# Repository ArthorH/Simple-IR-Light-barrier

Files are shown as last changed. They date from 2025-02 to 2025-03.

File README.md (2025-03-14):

# Simple IR Light barrier
Very simplistic light barrier based on NE555 and TSSP4038 sensor
SimpleRXTX
## Project Status: **completed** 
**Design** ✅ — **Fabrication** ✅ — **Assembly** ✅ — **Bringup** ✅ — **Testing** ✅  
## Key technologies:
&nbsp;&nbsp;&nbsp;&nbsp;
## Features:
- **Adjustable output impulse time**
- **TSSP4038**
- **Universal THT SMD footprints**
  
obraz
## Notice:
TSSP series **IS NOT** pin compatible with TSOP seriers sensors.

**DO NOT** use sensors with continious carrier rejection such as TSOP4838

TSSP/TSOP can reliably detect up to 1KHz modulated signal
## Completed:


## Author:
Artem Horiunov
## License:
CERN-OHL-P

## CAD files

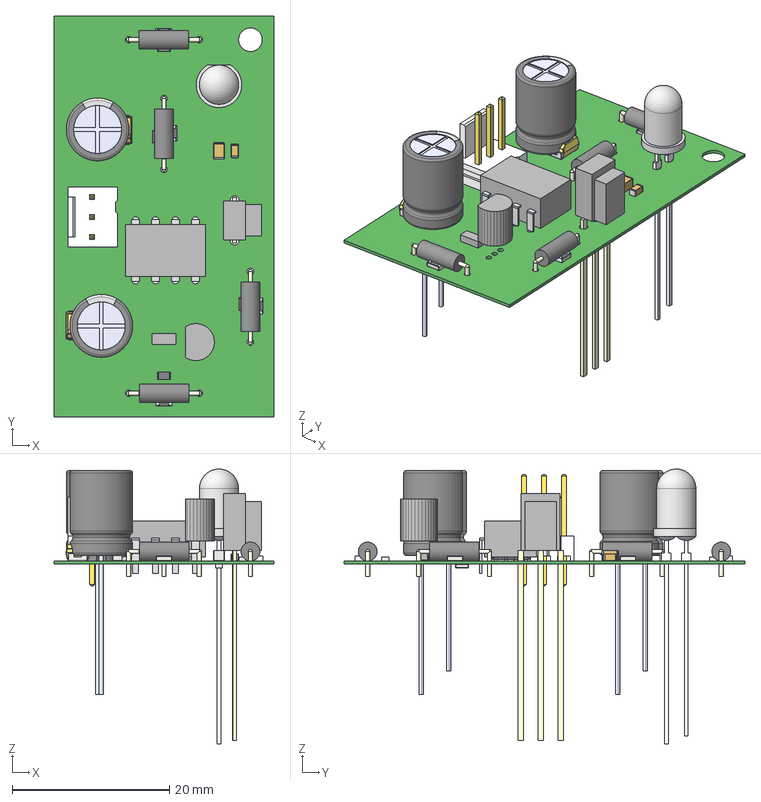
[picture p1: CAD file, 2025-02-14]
Mechanical/RX.step
28.0 x 51.0 x 35.0 mm
Extruded x 32
Molex 22-11-2032 1 new
Molex 22-11-2032 2 x 3
BODY_M08A_35
LEAD_M08A_57 x 8
MANIFOLD_SOLID_BREP_2784
MANIFOLD_SOLID_BREP_2935
MANIFOLD_SOLID_BREP_3086
MANIFOLD_SOLID_BREP_3237
Mid_Body x 5
Mark x 5
RES0805 x 4
151053xxx
Package x 2
Pins x 2
Marking x 2
Logo x 2

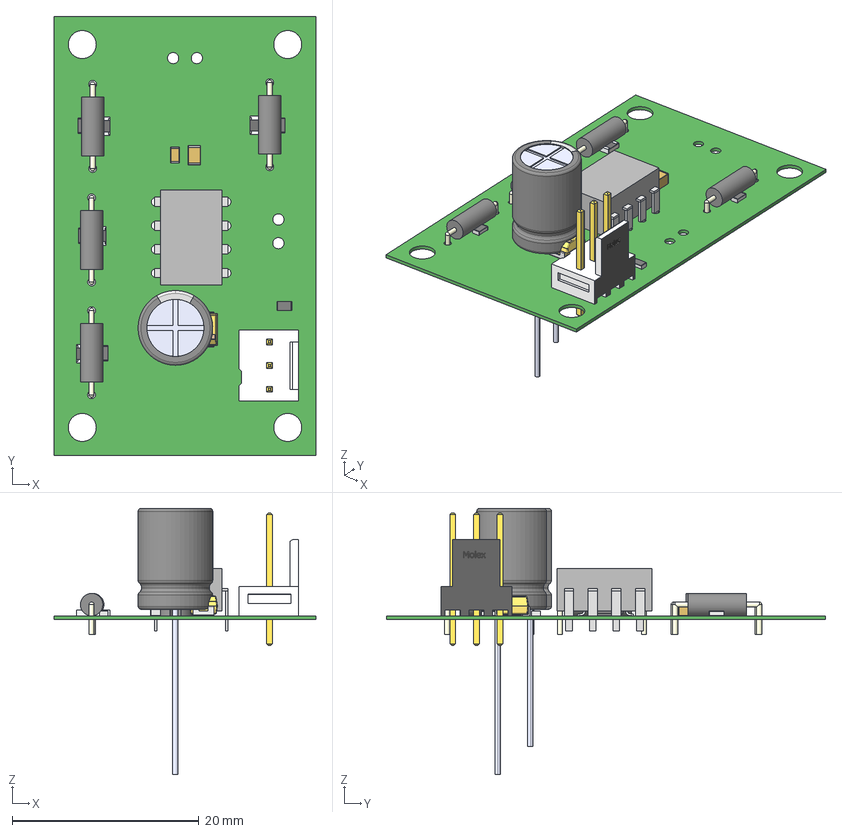
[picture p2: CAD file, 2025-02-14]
Mechanical/TX.step
28.0 x 47.0 x 28.5 mm
Package
Pins
Marking
Logo
Extruded x 25
BODY_M08A_35
LEAD_M08A_57 x 8
MANIFOLD_SOLID_BREP_2784
MANIFOLD_SOLID_BREP_2935
MANIFOLD_SOLID_BREP_3086
MANIFOLD_SOLID_BREP_3237
Mid_Body x 5
Mark x 5
RES0805 x 4
Molex 22-11-2032 1 new
Molex 22-11-2032 2 x 3

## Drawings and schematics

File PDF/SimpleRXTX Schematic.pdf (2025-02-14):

# BC547CG² ¹

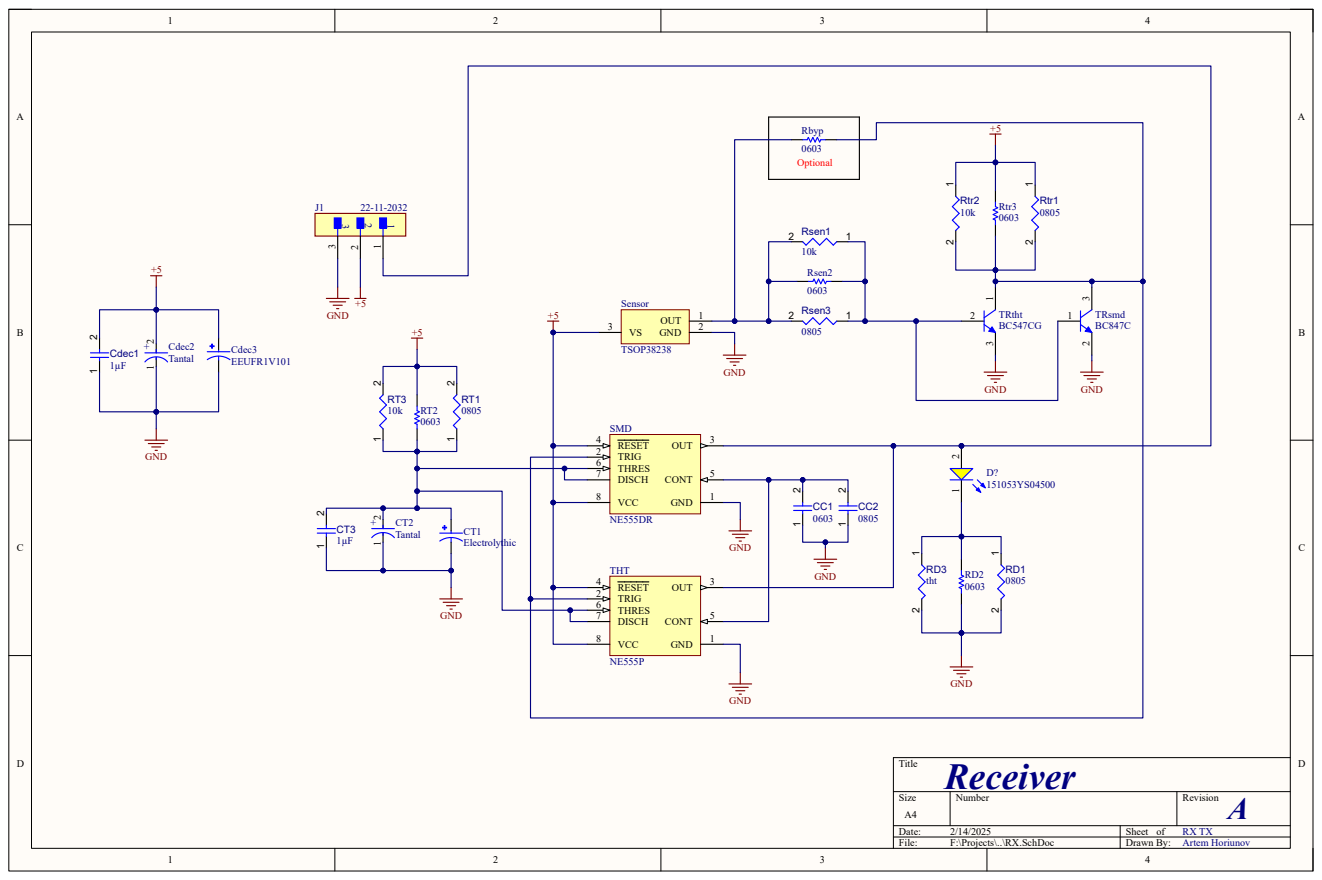
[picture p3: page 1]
Title; Size; Number; Revision; Date:; Sheet of; File:; F:\Projects\..\RX.SchDoc; Drawn By:; GND; TRIG 2; OUT; 3 RESET 4; CONT; THRES 6 DISCH 7; VCC 8; SMD; Sensor; TSOP38238; CT1 Electrolythic; Cdec3; EEUFR1V101; Tantal; GND ²; Rsen3; Rsen2; Rsen1; TRtht; Rtr1 Rtr3; Rtr2; tht; Cdec2; Tantal 1 2; Cdec1; GND 1 2; Rbyp; 0603 Optional; THT; TRsmd BC847C; Artem Horiunov; Receiver

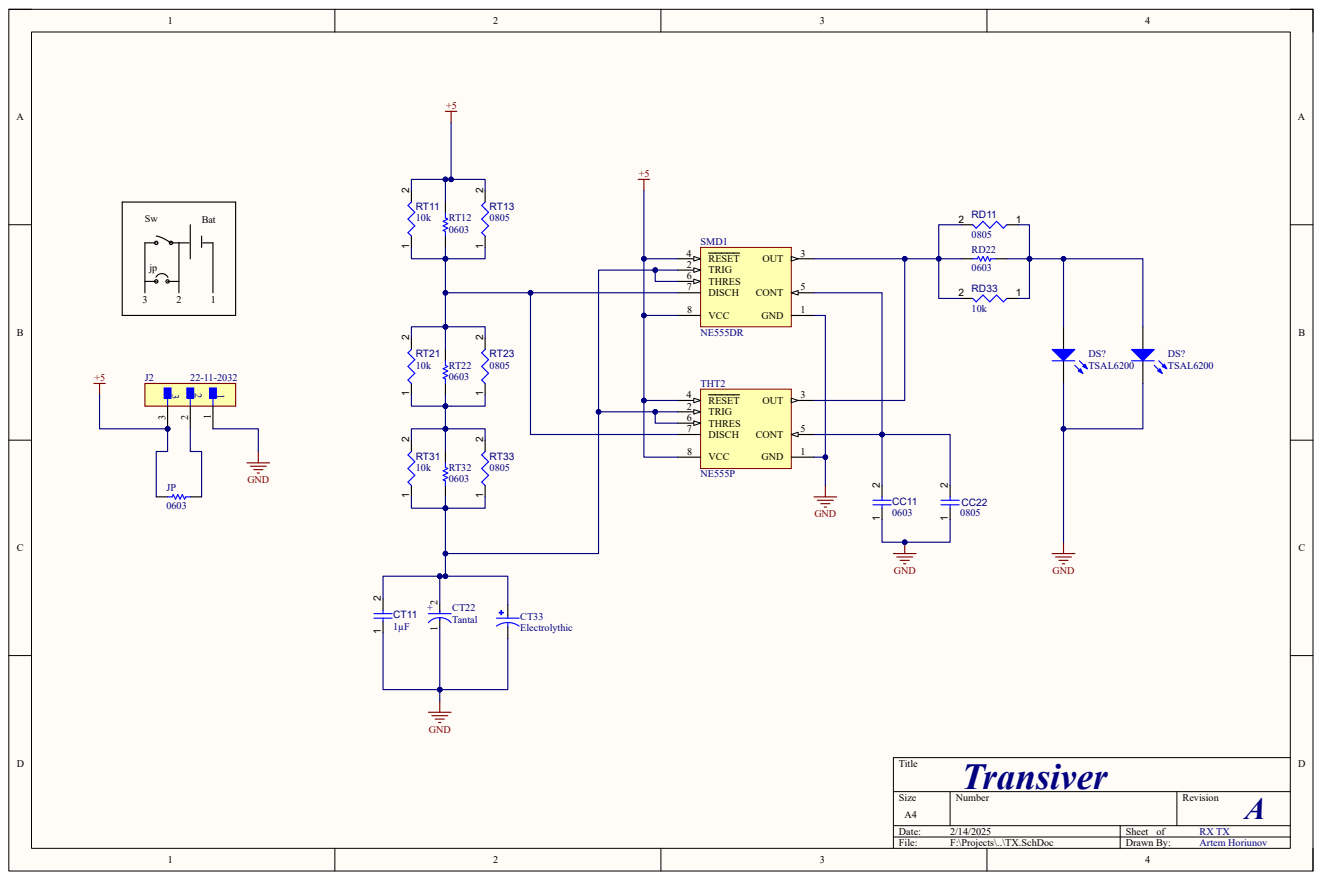
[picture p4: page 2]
Title; Size; Number; Revision; Date:; Sheet of; File:; F:\Projects\..\TX.SchDoc; Drawn By:; GND; TRIG 2; OUT; 3 RESET 4; CONT; THRES 6 DISCH 7; VCC 8; SMD1; THT2; DS? TSAL6200; GND ³; Bat; Electrolythic ²; Tantal 1 2; Artem Horiunov; Transiver

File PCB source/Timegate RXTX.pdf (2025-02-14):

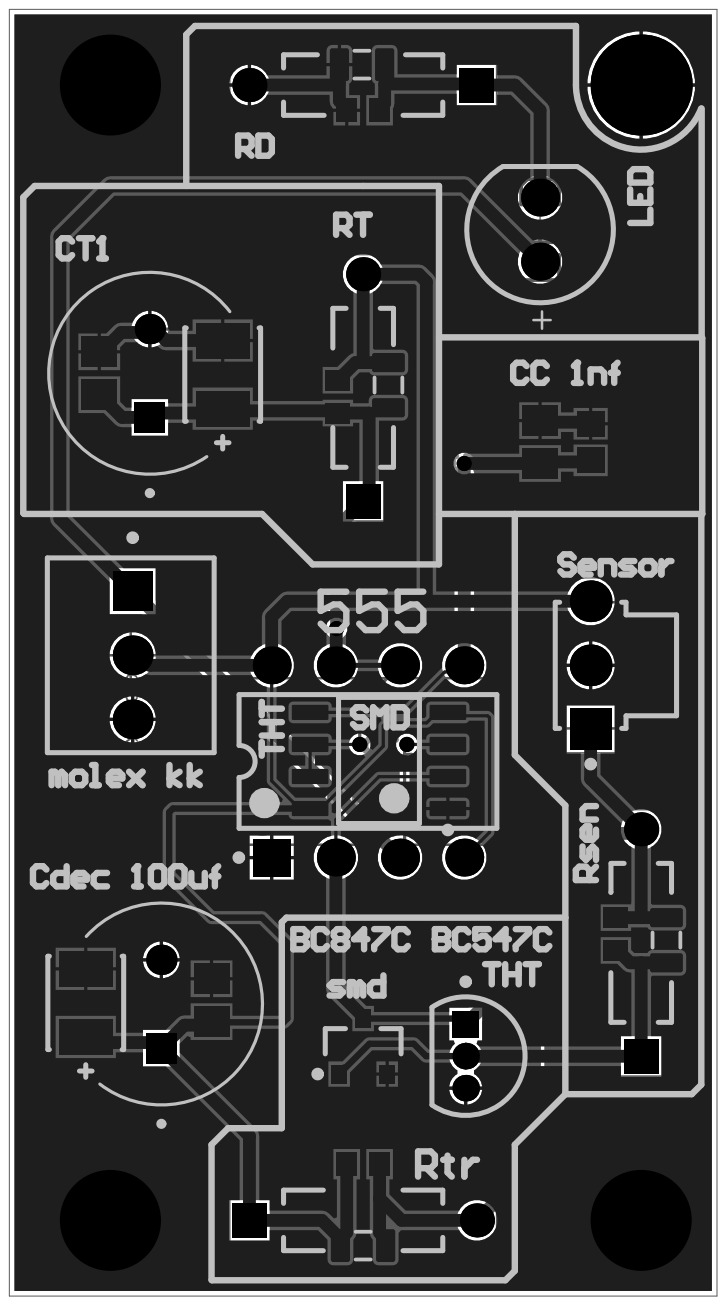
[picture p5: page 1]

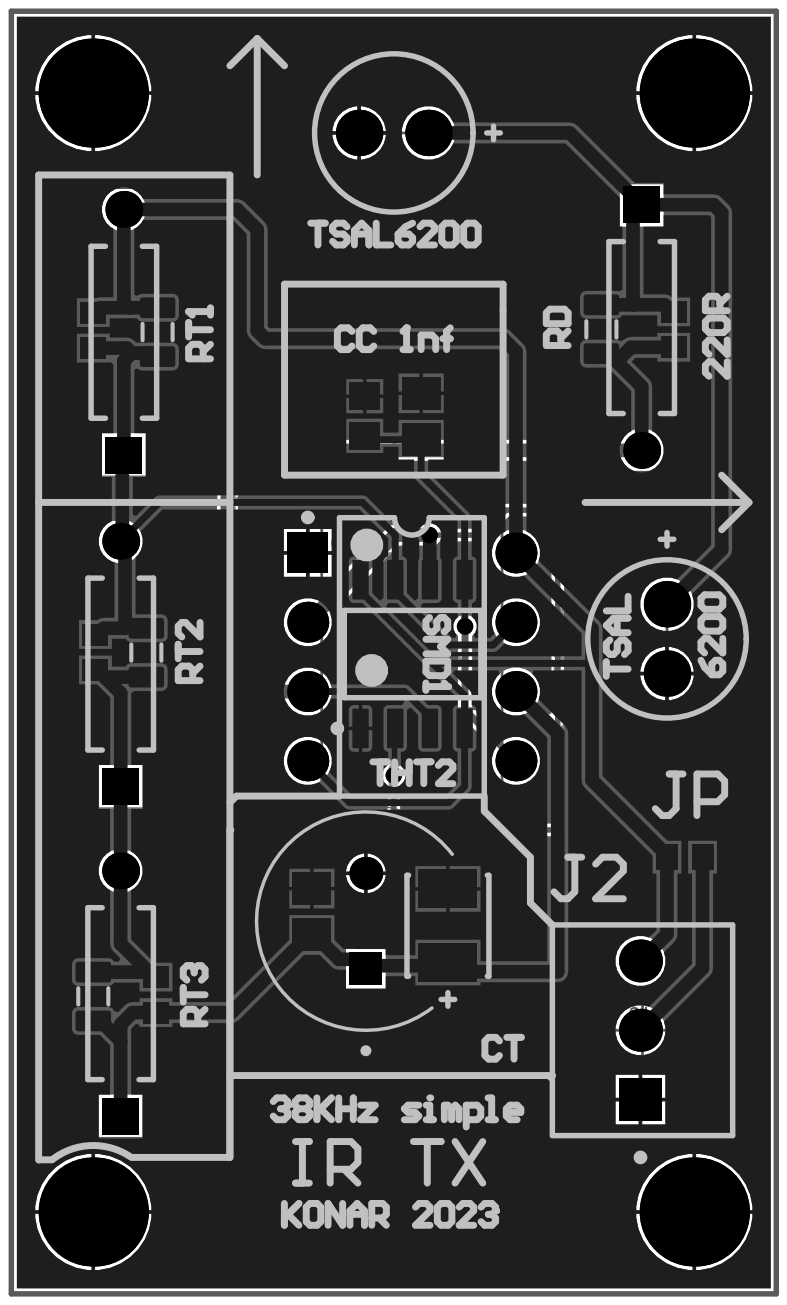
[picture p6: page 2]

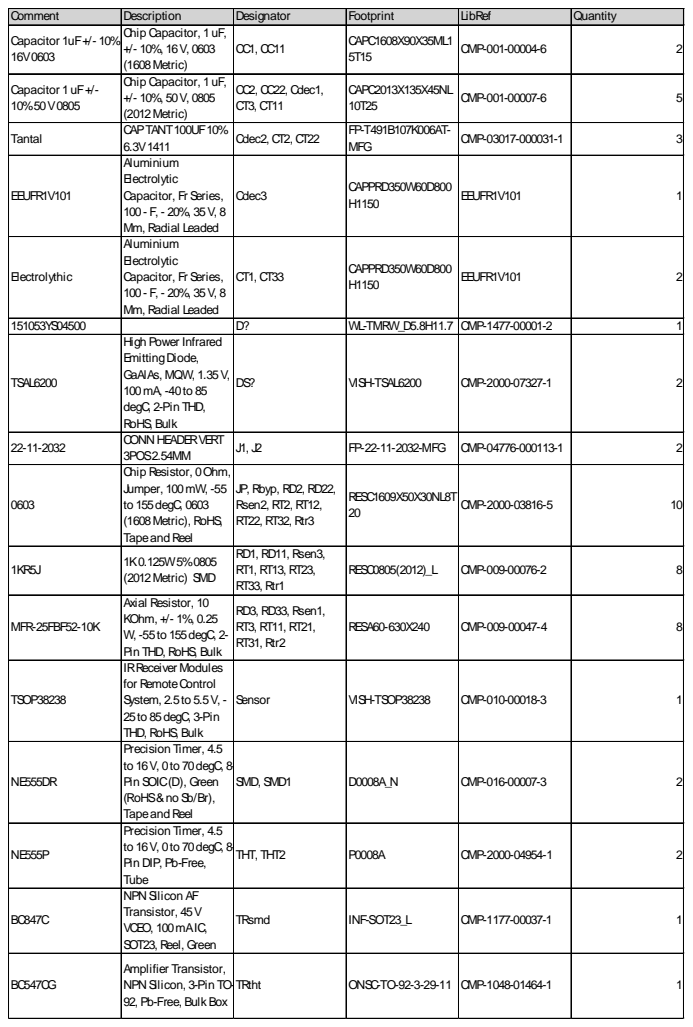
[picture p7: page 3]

Comment | Description | Designator | Footprint | LibRef | Quantity
Capacitor 1uF+/- 10% 16V0603 | Chip Capacitor, 1uF, +/- 10%, 16V, 0603 (1608Metric) | CC1, CC11 | CAPC1608X90X35ML1 5T15 | CMP-001-00004-6 | 2

Capacitor 1uF+/-10%50V0805 | Chip Capacitor, 1uF, +/- 10%, 50V, 0805 (2012Metric) | CC2, CC22, Cdec1, CT3, CT11 | CAPC2013X135X45NL 10T25 | CMP-001-00007-6 | 5

Tantal | CAPTANT100UF10% 6.3V1411 | Cdec2, CT2, CT22 | FP-T491B107K006AT-MFG | CMP-03017-000031-1 | 3

EEUFR1V101 | Aluminium Electrolytic Capacitor, Fr Series, 100- F, - 20%, 35V, 8 Mm, Radial Leaded | Cdec3 | CAPPRD350W60D800 H1150 | EEUFR1V101 | 1

Electrolythic | Aluminium Electrolytic Capacitor, Fr Series, 100- F, - 20%, 35V, 8 Mm, Radial Leaded | CT1, CT33 | CAPPRD350W60D800 H1150 | EEUFR1V101 | 2

151053YS04500 | | D? | WL-TMRW_D5.8H11.7 | CMP-1477-00001-2 | 1
TSAL6200 | High Power Infrared EmittingDiode, GaAlAs, MQW, 1.35V, 100mA, -40to 85 degC, 2-Pin THD, RoHS, Bulk | DS? | VISH-TSAL6200 | CMP-2000-07327-1 | 2

22-11-2032 | CONN HEADERVERT 3POS2.54MM | J1, J2 | FP-22-11-2032-MFG | CMP-04776-000113-1 | 2

0603 | Chip Resistor, 0Ohm, Jumper, 100mW, -55 to 155degC, 0603 (1608Metric), RoHS, Tapeand Reel | JP, Rbyp, RD2, RD22, Rsen2, RT2, RT12, RT22, RT32, Rtr3 | RESC1609X50X30NL8T 20 | CMP-2000-03816-5 | 10

1KR5J | 1K0.125W5%0805 (2012Metric) SMD | RD1, RD11, Rsen3, RT1, RT13, RT23, RT33, Rtr1 | RESC0805(2012)_L | CMP-009-00076-2 | 8

MFR-25FBF52-10K | Axial Resistor, 10 KOhm, +/- 1%, 0.25 W, -55to 155degC, 2-Pin THD, RoHS, Bulk | RD3, RD33, Rsen1, RT3, RT11, RT21, RT31, Rtr2 | RESA60-630X240 | CMP-009-00047-4 | 8

TSOP38238 | IRReceiver Modules for RemoteControl System, 2.5to 5.5V, -25to 85degC, 3-Pin THD, RoHS, Bulk | Sensor | VISH-TSOP38238 | CMP-010-00018-3 | 1

NE555DR | Precision Timer, 4.5 to 16V, 0to 70degC, 8-Pin SOIC(D), Green (RoHS&no Sb/Br), Tapeand Reel | SMD, SMD1 | D0008A_N | CMP-016-00007-3 | 2

NE555P | Precision Timer, 4.5 to 16V, 0to 70degC, 8-Pin DIP, Pb-Free, Tube | THT, THT2 | P0008A | CMP-2000-04954-1 | 2

BC847C | NPN Silicon AF Transistor, 45V VCEO, 100mAIC, SOT23, Reel, Green | TRsmd | INF-SOT23_L | CMP-1177-00037-1 | 1

BC547CG | Amplifier Transistor, NPN Silicon, 3-Pin TO-92, Pb-Free, BulkBox | TRtht | ONSC-TO-92-3-29-11 | CMP-1048-01464-1 | 1

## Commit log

2024-08-17 REV A
    [RX.PcbDoc, RX.SchDoc, RXTX board.PcbDoc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]
2025-02-14 Do cleanup
    [RX.PcbDoc, RX.SchDoc, RX.step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]
